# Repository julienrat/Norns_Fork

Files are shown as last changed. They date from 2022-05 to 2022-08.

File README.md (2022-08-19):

# Norns_Fork
**Dépôt Norns - installation Damien Skoraki**

L'idée principale est de forker l'officiel NORNS pour **la sublimer, la destructurer et la revisiter** avec un chapeau hifiberry DAC ADC Pro et des composants pas trop coûteux...

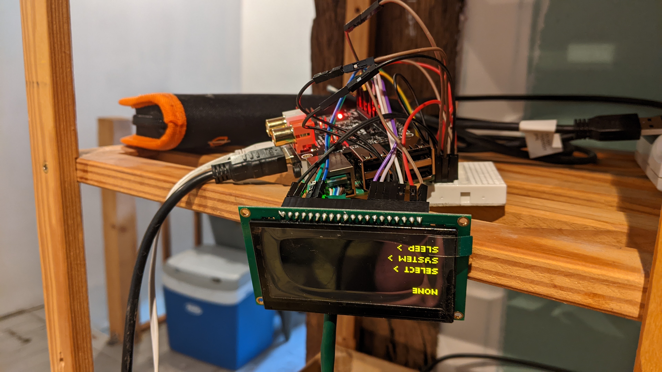
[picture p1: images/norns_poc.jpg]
Norns destructuré


La doc du HIFIBERRY est ici : (https://www.hifiberry.com/docs/software/configuring-linux-3-18-x/)

## Modification du Kernel Original
Le noyau original  de norns ne contient pas les modules permettant le bon fonctionnement du chapeau HIFIBERRY, mais contient les modules de l'ecran !

D'autres noyaux sont présents dans la distribution officielle de Norns .... mais sans les modules de l'écran !

D'où le casse tête ! donc 2 solutions !

- Recompiler un noyau vierge sur une install vierge au risque de louper des trucs en s'inspirant du [vieux tuto](https://github.com/okyeron/norns-image/wiki/1.-Norns-2.0-Full-Build-on-RasPi)
- Partir du  dernier noyau de l'installation y ajouter l'écran en bénéficiant des modules installés d'office pour ce noyau et garder tous les fichiers de config de l'installation en s'inpirant de ce [tuto vieux aussi :D](https://github.com/okyeron/norns-image/wiki/Reference:--Compile-OLED-display-drivers)

J'ai décidé de choisir la seconde option ! on pars de l'existant, on modifie le vieux tuto ! et si ça bouge ce sera facile d'upgrader une image des familles !

**DONC :**

À partir de la realease NORNS **norns 220306**  :

[Images SD Norns](https://github.com/monome/norns-image/releases)

On flash une carte SD avec le logiciel Balena ETCHER : 

[Balena Etcher](https://www.balena.io/etcher/)

### On se connecte en ssh
```
ssh we@<adresse_ip>
Mot de passe : sleep
```
On étend la partition pour travailler à l'aise !
```
sudo raspi-config
```
et on reboot !

### Installation des paquets de compilation 
```
sudo apt-get update
sudo apt-get upgrade
sudo apt-get install flex bison raspberrypi-kernel-headers
sudo apt install build-essential fakeroot dpkg-dev perl libssl-dev bc gnupg dirmngr libncurses5-dev libelf-dev 
```
### On commente la derniere ligne du fichier /boot/config.txt

On édite

```
sudo nano /boot/config.txt
```
On va commenter cette ligne pour lancer la derniere version du kernel connue ! et non celle bidouillée par NORNS

```
#kernel=gnagnagna
```
et pendant qu'on est sur le fichier, on va commenter la ligne :
```
#dtoverlay=monome-snd-4271
```
et ajouter ces deux lignes pour utiliser la carte son du hifiberry adcplusdac-pro
```
dtoverlay=hifiberry-dacplusadcpro
force_eeprom_read=0
```
et on reboot ! et on jete un coup d'oeil sur la carte hifiberry, normalement les leds rouges doivent scintiller...

### Récupération du noyau pour compiler les modules:

```
git clone --depth=1 https://github.com/raspberrypi/linux
```

### On compile
on va récupérer les fichiers de config
```
cp /usr/src/linux-headers-$(uname -r)/Module.symvers .
cp /usr/src/linux-headers-$(uname -r)/.config .
```
ensuite on lance le menuconfig
```
make menuconfig
```
et on active l'écran !

```
Device Drivers  ---> Staging Drivers ---> Support for small TFT LCD display modules  --->
        <M>   SH1106 driver
        <M>   SSD1322 driver
```
et enfin on compile !
```
make -j4 prepare

make -j4 -C ~/linux SUBDIRS=drivers/staging/fbtft modules

```
on attends 3-4 heures ...

### Copie des modules et test
On va copier les modules compilés au bon endroit
```
sudo cp -v ~/linux/drivers/staging/fbtft/*.ko /lib/modules/$(uname -r)/kernel/drivers/staging/fbtft/

sudo depmod -a
```
et zou on teste !
```
sudo modprobe fbtft custom name=fb_ssd1322 debug=1 speed=16000000 gpios=reset:15,dc:14
dmesg
```

### On va tweaker !
L'écran est desormais monté sur /dev/fb1 au lieu de /dev/fb0, il va falloir modifier la configuration de **matron** interface graphique, pour rediriger l'affichage sur le bon point de montage :

On édite

```
nano ~/norns/matronrc.lua
```
et on change la ligne 2 pour pointer sur /dev/fb1

```
_boot.add_io('screen:fbdev', {dev='/dev/fb1'})
```
On reboot et voilà !

### TWEAKS !
Pour changer le nom du Norns, il suffit d'editer le fichier hostname situé dans /etc/ 
```
sudo nano /etc/hostname
```
Modifier le nom , puis sauver en appuyant sur Ctrl+X puis Y pour sauver

Il est aussi possible de modifier le nom directement sur la carte SD en ouvrant le repertoire /etc

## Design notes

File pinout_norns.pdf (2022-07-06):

Feuille1

PIN MAP NORNS

Ecran OLED

ENC 1

1 3,3V | 1 | 2 | 5v | ENC 2
2 HIFIBERRY/SDA | 3 | 4 | 5v | ENC 3
3 HIFIBERRY/SCL | 5 | 6 | GND | HIFIBERRY
4 A1_ENC1 | 7 | 8 | RESERVEE | BP K1,K2,K3
5 GND | 9 | 10 | RESERVEE
6 | 11 | 12 | HIFIBERRY
7 B1_ENC1 | 13 | 14 | GND
8 K1_BP | 15 | 16 | B2_ENC2
9 3,3V | 17 | 18 | A2_ENC2
10 OLED_MOSI | 19 | 20 | GND
11 | 21 | 22 | B3_ENC3
12 SCK | 23 | 24 | CE_OLED
13 GND | 25 | 26
14 RESERVEE | 27 | 28 | RESERVEE
15 OLED_DC | 29 | 30 | GND
16 OLED_RESET | 31 | 32 | A3_ENC3
17 K3_BP | 33 | 34 | GND
18 HIFIBERRY | 35 | 36
19 K2_BP | 37 | 38 | HIFIBERRY
20 GND | 39 | 40 | HIFIBERRY

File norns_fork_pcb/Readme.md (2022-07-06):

# Dossier PCB Norns Syst et Norns Eko
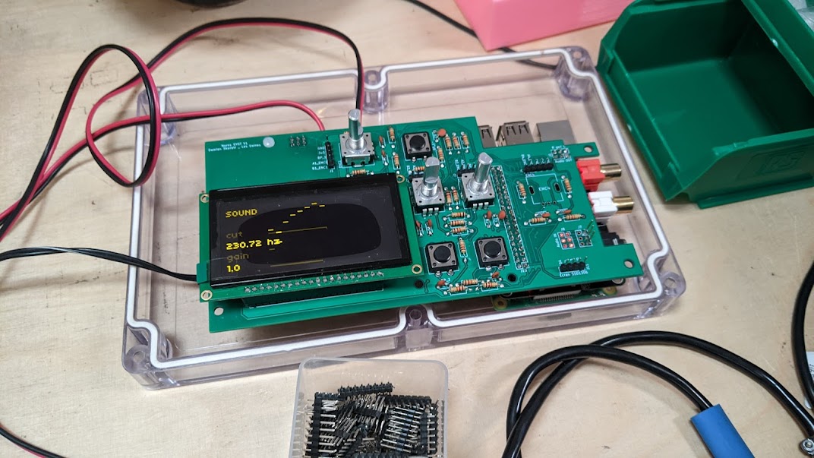
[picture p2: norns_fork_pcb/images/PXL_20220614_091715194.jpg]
Norns Syst


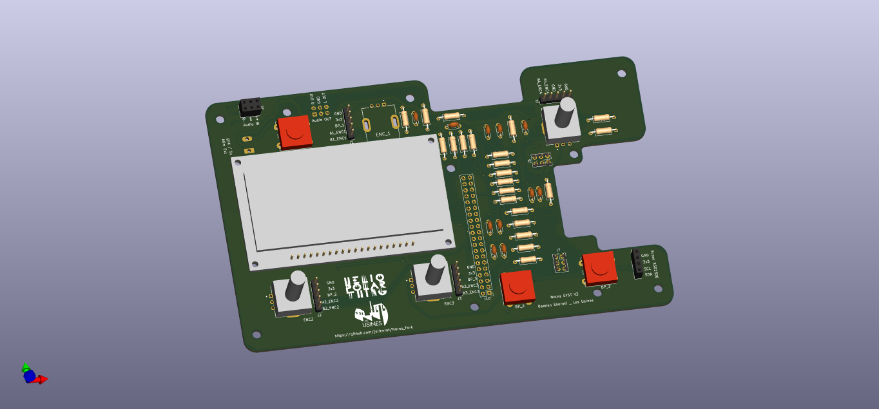
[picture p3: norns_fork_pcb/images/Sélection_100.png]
Norns Syst

## Instructions de soudure :

* Soudure SYST : [https://rawcdn.githack.com/julienrat/Norns_Fork/main/norns_fork_pcb/norns_SYST_kicad_sources/ibom.html]

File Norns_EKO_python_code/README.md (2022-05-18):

# Ici Tuto d'utilisation des modules TTGO

## Utilisation Basique
Le TTGO flashé possede une interface qu'il faut savoir prendre en main pour lancer ses scripts !

### Acces au menu de selection des scripts
Au démarrage du TTGO, appuyez sur le bouton droit, le menu de selection s'affiche alors.

A l'aide des boutons, sélectionnez le script désiré et sauvegardez en apuyant simultanément sur les deux boutons.

## Connexion à Thonny pour créer un script
A préalable, il faudra télécharger les drivers CH341 suivant votre systeme d'exploitation :

Puis installer le logiciel [thonny](https://thonny.org/)

## Connexion en WEBRPL

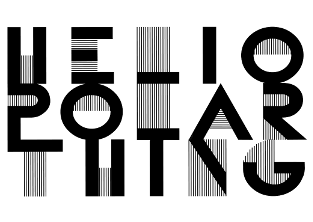
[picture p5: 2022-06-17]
images/visuel3-Small-1.png

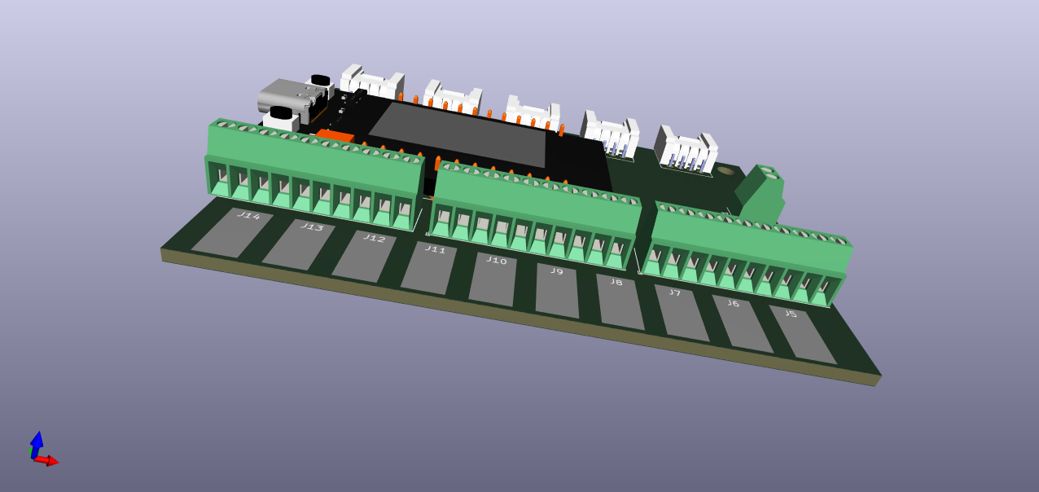
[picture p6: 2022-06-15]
norns_fork_pcb/images/norns_eko_2.png

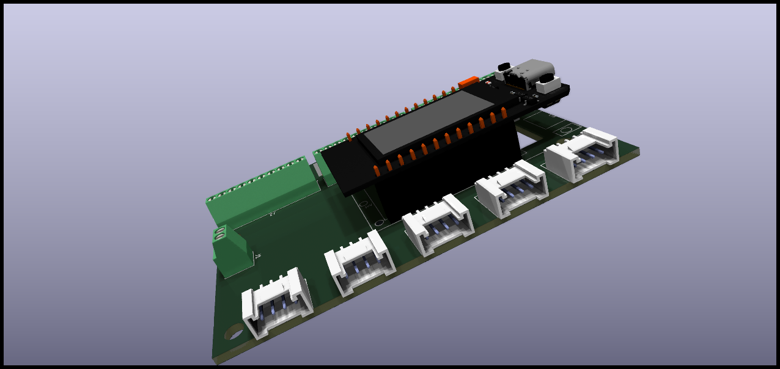
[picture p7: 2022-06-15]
norns_fork_pcb/images/norns_eko_support.png

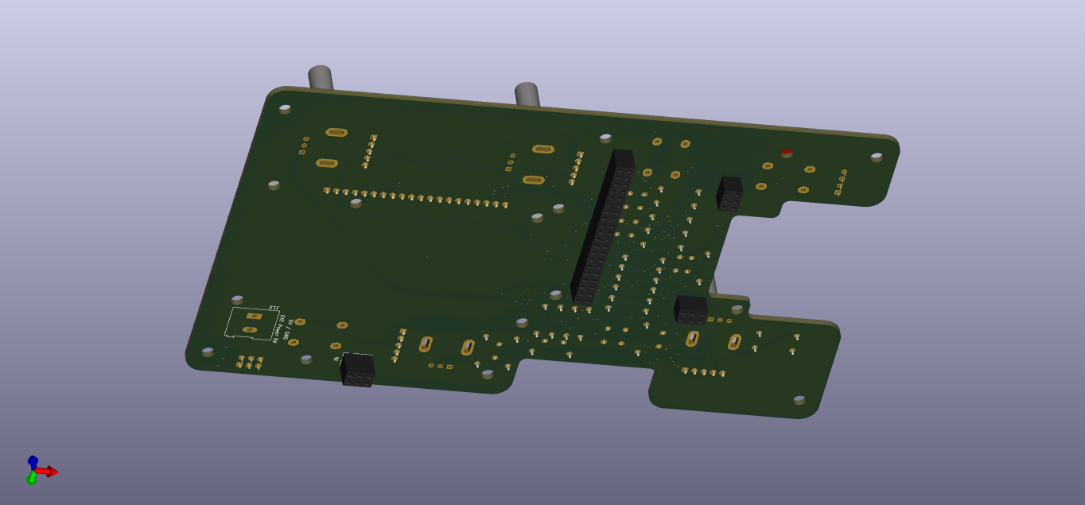
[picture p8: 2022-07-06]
norns_fork_pcb/images/Sélection_101.png

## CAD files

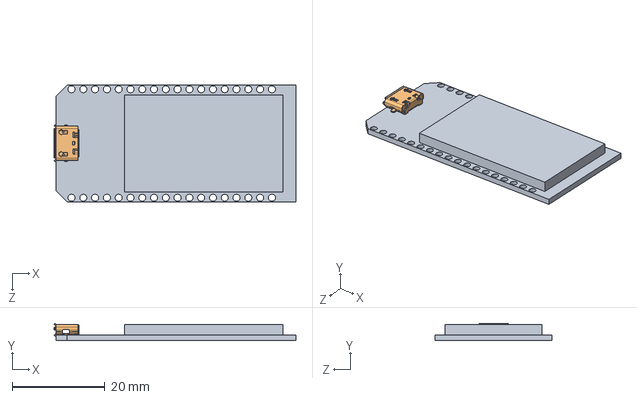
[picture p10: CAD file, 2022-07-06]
norns_fork_pcb/norns_EKO_kicad_sources/footprint/ttgo-tdisplay-kicad-master/TTGO1.SLDASM
52.1 x 3.77 x 25.1 mm
TTGO-ESP32LORA
microusb

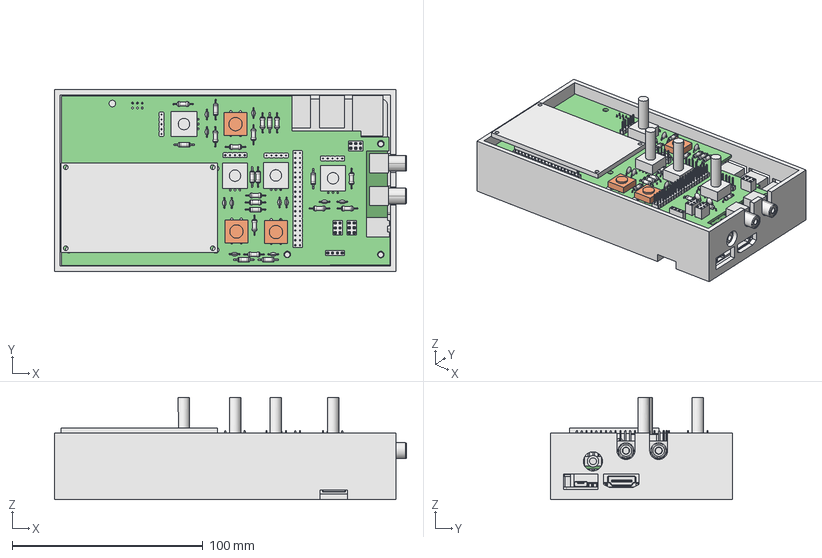
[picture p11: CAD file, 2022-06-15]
3D_case/3D_case_syst_freecad/test_2.FCStd
184.4 x 95.5 x 53.7 mm
_autosave-norns_fork PCB
RASPBERRY PI 3

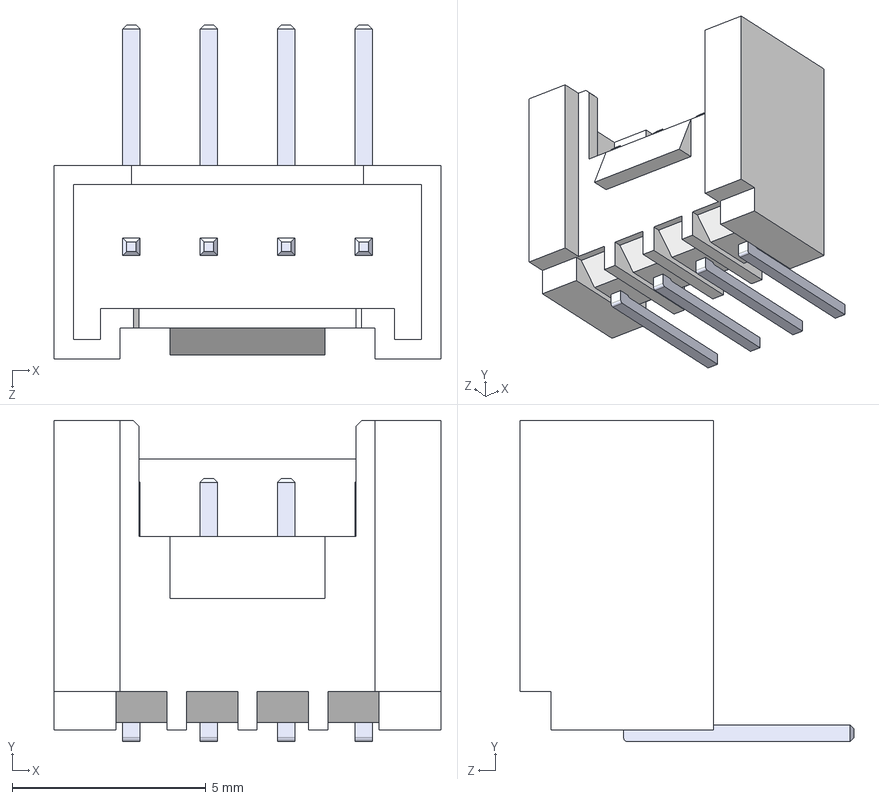
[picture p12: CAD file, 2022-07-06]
norns_fork_pcb/norns_EKO_kicad_sources/footprint/Grove Connector (lying).STEP
10.0 x 8.30 x 8.62 mm

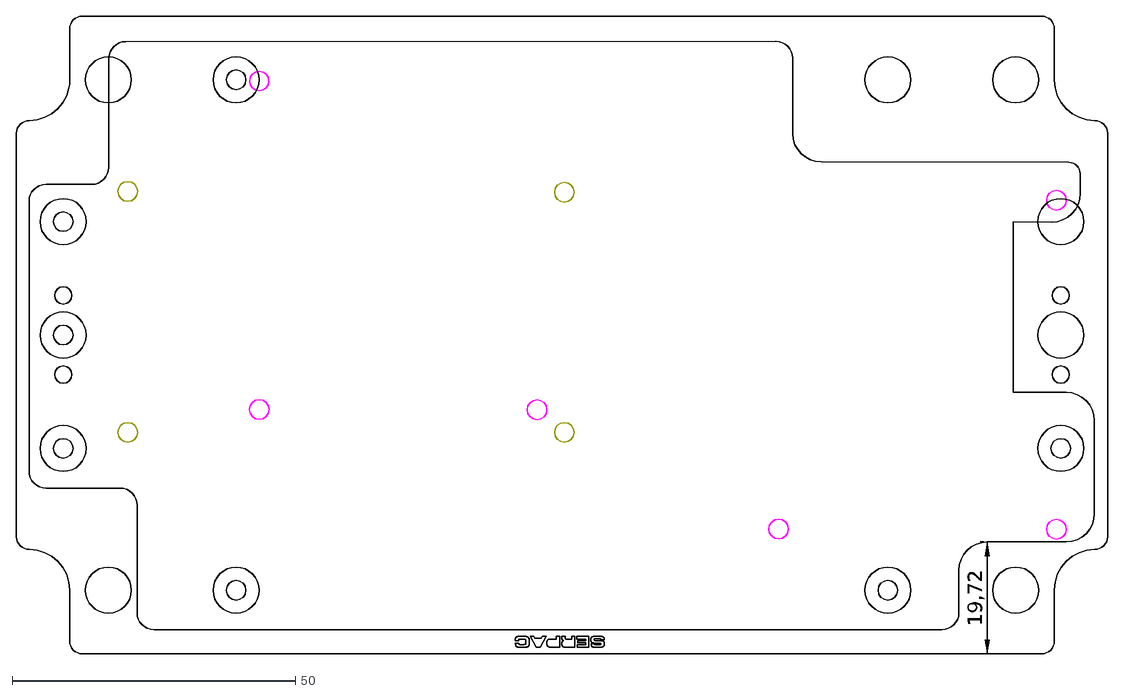
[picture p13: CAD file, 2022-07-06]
norns_fork_pcb/norns_SYST_kicad_sources/edgecut/#Fond boite_montage.dxf
19,72

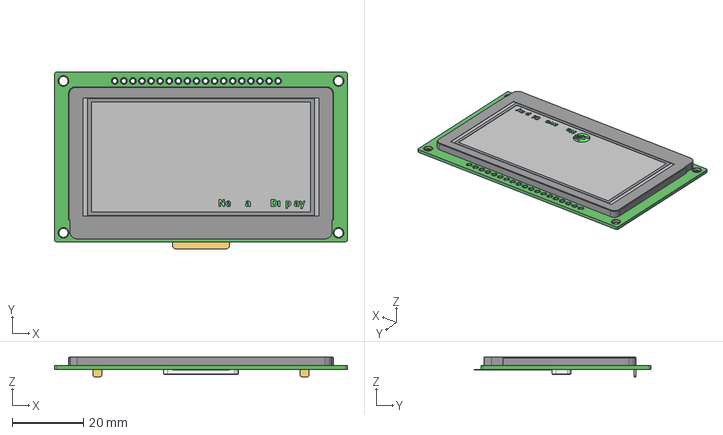
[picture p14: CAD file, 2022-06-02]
norns_fork_pcb/norns_SYST_kicad_sources/footprint/Disp_Newhaven Display_NHD-2.7-12864WDY3/eec.models/Newhaven_Display_-_NHD-2.7-12864WDY3.step
82.0 x 49.5 x 5.50 mm

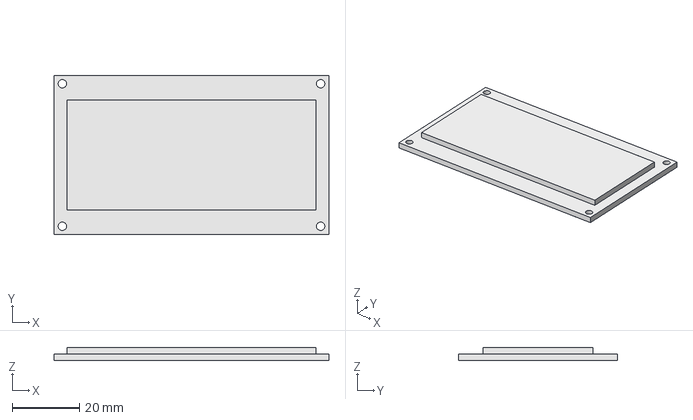
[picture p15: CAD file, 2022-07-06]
norns_fork_pcb/norns_SYST_kicad_sources/footprint/ecran.step
82.0 x 47.5 x 4.00 mm

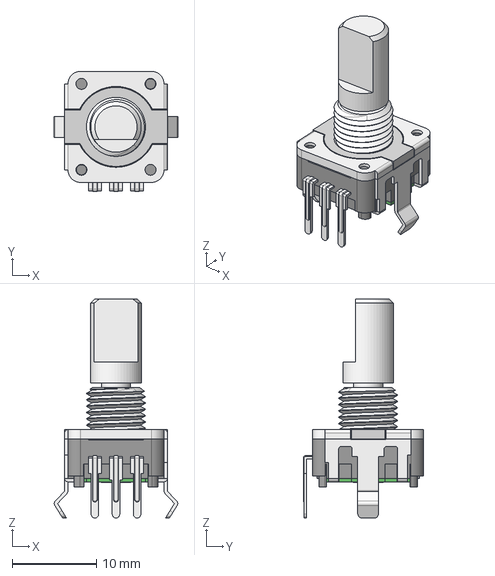
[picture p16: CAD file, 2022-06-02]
norns_fork_pcb/norns_SYST_kicad_sources/footprint/Enc_Bourns_PEC11R-4015F-N0024/eec.models/Bourns_-_PEC11R-4015F-N0024.step
14.7 x 14.3 x 26.0 mm

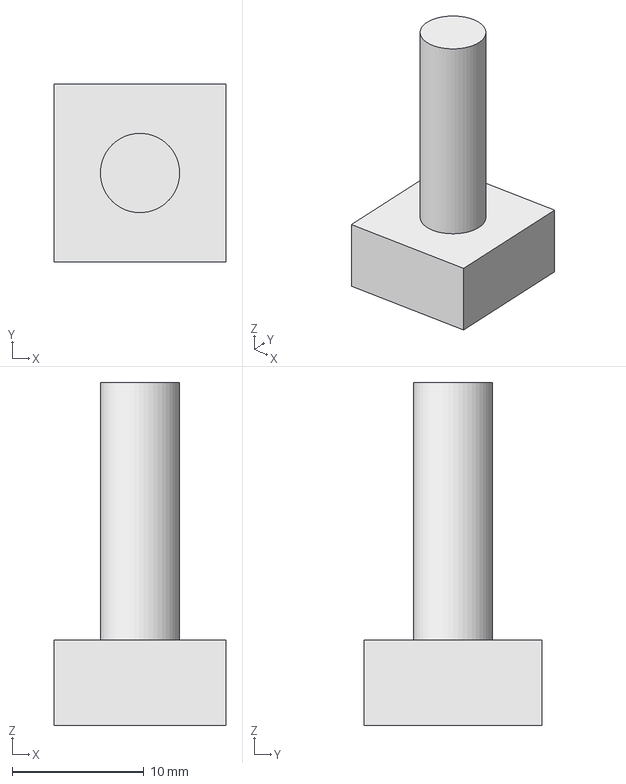
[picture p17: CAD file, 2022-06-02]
norns_fork_pcb/norns_SYST_kicad_sources/footprint/Enc_Bourns_PEC11R-4015F-N0024/encodeur.step
13.0 x 13.5 x 26.0 mm

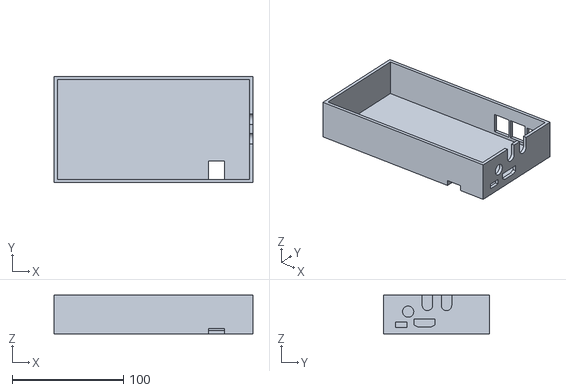
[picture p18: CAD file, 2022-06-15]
3D_case/3D_case_syst_freecad/test_2-Body.stl
178.7 x 95.3 x 35.0

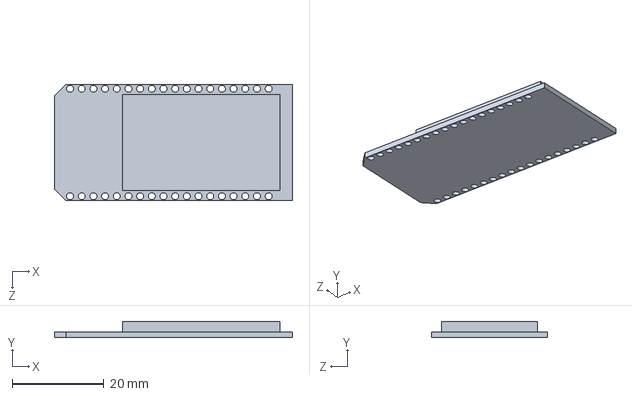
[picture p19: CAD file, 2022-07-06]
norns_fork_pcb/norns_EKO_kicad_sources/footprint/ttgo-tdisplay-kicad-master/TTGO-ESP32LORA.SLDPRT
51.8 x 3.55 x 25.1 mm

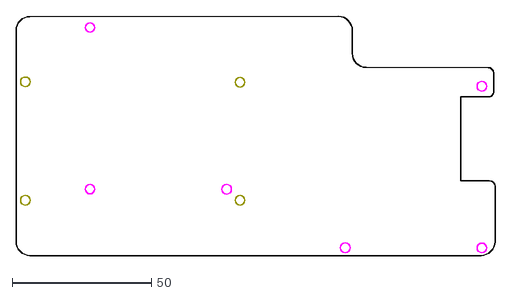
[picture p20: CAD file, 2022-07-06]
norns_fork_pcb/norns_SYST_kicad_sources/edgecut/norns_fork-Edge_Cuts.dxf
171.8 x 85.8

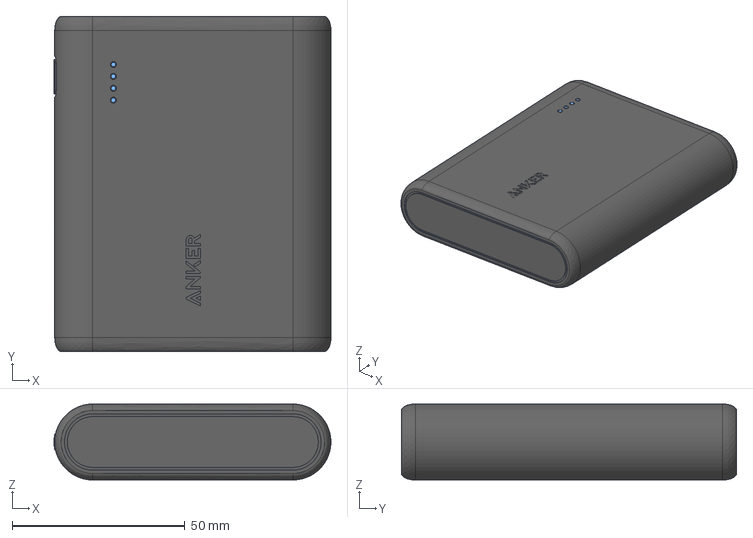
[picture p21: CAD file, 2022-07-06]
norns_fork_pcb/norns_SYST_kicad_sources/footprint/Anker Powercore 13000 Battery.step
80.2 x 97.0 x 22.0 mm

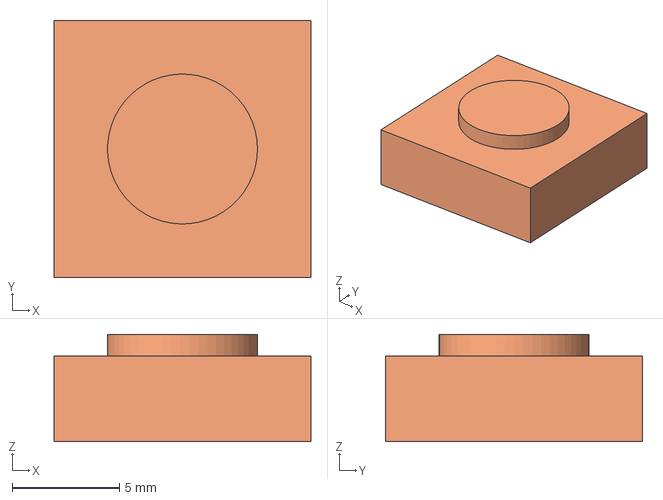
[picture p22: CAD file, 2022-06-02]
norns_fork_pcb/norns_SYST_kicad_sources/footprint/Enc_Bourns_PEC11R-4015F-N0024/bouton.step
12.0 x 12.0 x 5.00 mm

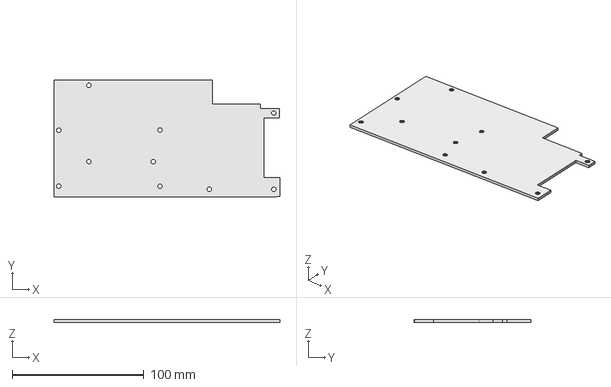
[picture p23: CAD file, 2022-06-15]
3D_case/3D_case_syst_freecad/test_1.FCStd
171.8 x 88.7 x 2.00 mm

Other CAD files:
norns_fork_pcb/norns_EKO_kicad_sources/footprint/ttgo-tdisplay-kicad-master/microusb.SLDPRT
norns_fork_pcb/norns_SYST_kicad_sources/edgecut/norns_fork-Edge_Cutsrnd.dxf
norns_fork_pcb/norns_SYST_kicad_sources/footprint/Enc_Bourns_PEC11R-4015F-N0024/ecran.step
norns_fork_pcb/norns_SYST_kicad_sources/footprint/rb85p12_24.step
3D_case/3D_case_syst_freecad/entretoises.FCStd
norns_fork_pcb/norns_SYST_kicad_sources/edgecut/#Fond boite.dxf
norns_fork_pcb/norns_SYST_kicad_sources/edgecut/Fond boite.dxf
norns_fork_pcb/norns_SYST_kicad_sources/edgecut/Fond boite_montage.dxf
norns_fork_pcb/norns_SYST_kicad_sources/edgecut/Norns_edgecut_final.dxf
norns_fork_pcb/norns_SYST_kicad_sources/edgecut/norns_fork-F_Silkscreen.dxf
norns_fork_pcb/norns_SYST_kicad_sources/footprint/RASPBERRY PI 3.STEP

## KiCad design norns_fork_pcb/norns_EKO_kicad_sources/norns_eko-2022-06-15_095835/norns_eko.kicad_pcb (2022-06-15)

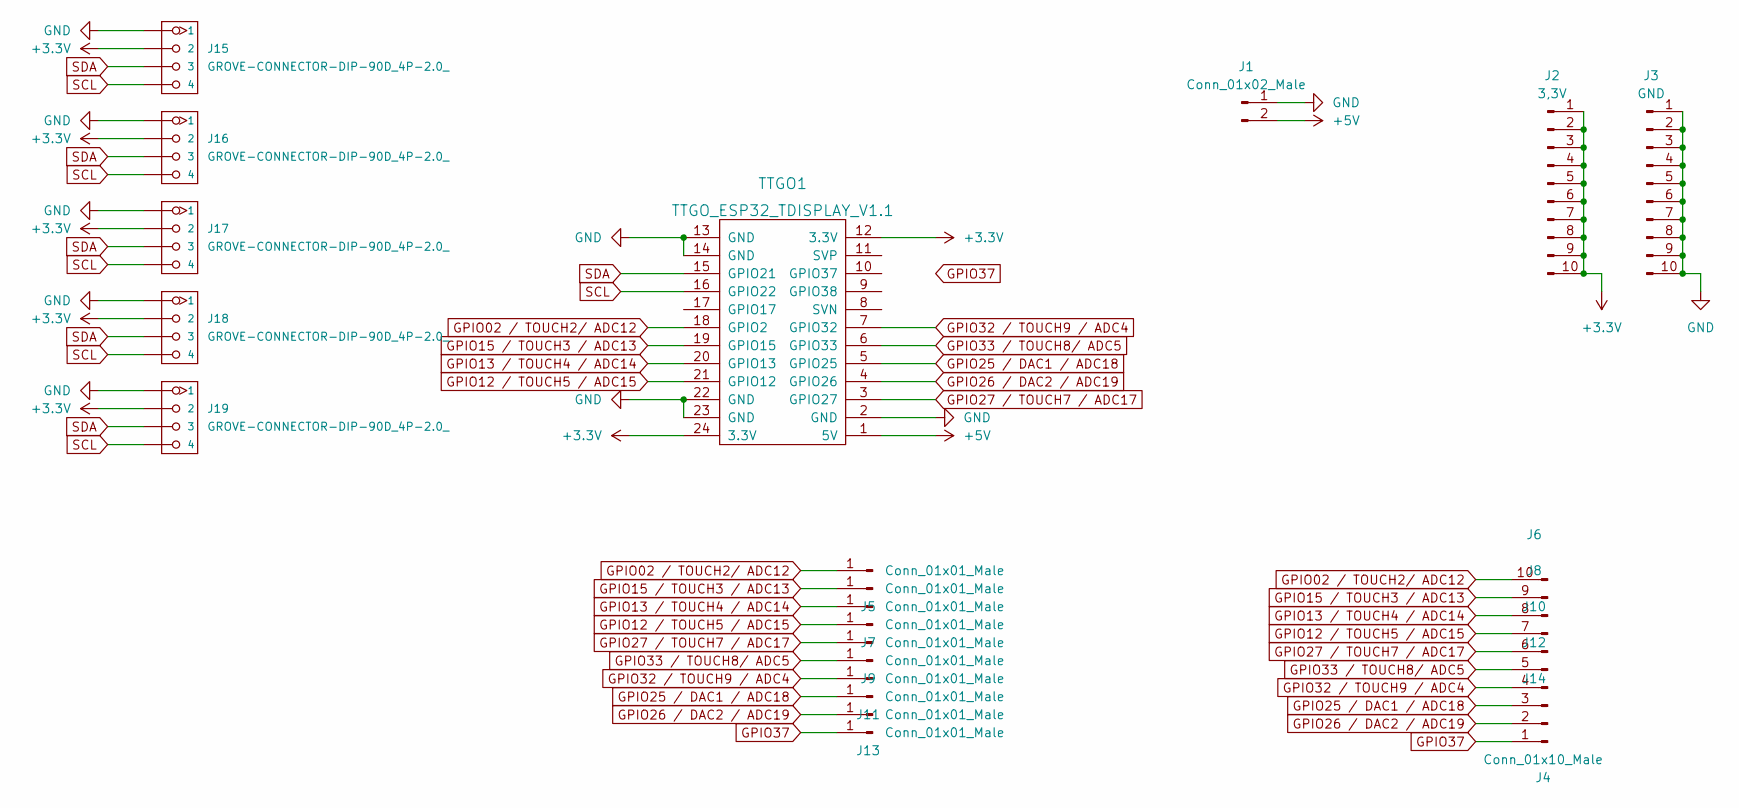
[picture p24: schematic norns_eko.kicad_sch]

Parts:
J1: Conn_01x02_Male; TerminalBlock_Phoenix_MPT-0,5-2-2.54_1x02_P2.54mm_Horizontal
J2: 3,3V; TerminalBlock_Phoenix_MPT-0,5-10-2.54_1x10_P2.54mm_Horizont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
J3: GND; TerminalBlock_Phoenix_MPT-0,5-10-2.54_1x10_P2.54mm_Horizont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
J4: Conn_01x10_Male; TerminalBlock_Phoenix_MPT-0,5-10-2.54_1x10_P2.54mm_Horizont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
J5, J6, J7, J8, J9, J10, J11, J12, J13, J14: Conn_01x01_Male; SolderWirePad_1x01_SMD_5x10mm
J15, J16, J17, J18, J19: GROVE-CONNECTOR-DIP-90D_4P-2.0_; HW4-2.0-90D
TTGO1: TTGO_ESP32_TDISPLAY_V1.1; TTGO_ESP32_TDisplay_v1.1

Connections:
+3V3: J2.1, J2.2, J2.3, J2.4, J2.5, J2.6, J2.7, J2.8, J2.9, J2.10, J15.2, J16.2, J17.2, J18.2, J19.2, TTGO1.12 (3.3V), TTGO1.24 (3.3V)
+5V: J1.2, TTGO1.1 (5V)
GND: J1.1, J3.1, J3.2, J3.3, J3.4, J3.5, J3.6, J3.7, J3.8, J3.9, J3.10, J15.1, J16.1, J17.1, J18.1, J19.1, TTGO1.2 (GND), TTGO1.13 (GND), TTGO1.14 (GND), TTGO1.22 (GND), TTGO1.23 (GND)
GPIO02 / TOUCH2/ ADC12: J4.10, J5.1, TTGO1.18 (GPIO2)
GPIO12 / TOUCH5 / ADC15: J4.7, J8.1, TTGO1.21 (GPIO12)
GPIO13 / TOUCH4 / ADC14: J4.8, J7.1, TTGO1.20 (GPIO13)
GPIO15 / TOUCH3 / ADC13: J4.9, J6.1, TTGO1.19 (GPIO15)
GPIO25 / DAC1 / ADC18: J4.3, J12.1, TTGO1.5 (GPIO25)
GPIO26 / DAC2 / ADC19: J4.2, J13.1, TTGO1.4 (GPIO26)
GPIO27 / TOUCH7 / ADC17: J4.6, J9.1, TTGO1.3 (GPIO27)
GPIO32 / TOUCH9 / ADC4: J4.4, J11.1, TTGO1.7 (GPIO32)
GPIO33 / TOUCH8/ ADC5: J4.5, J10.1, TTGO1.6 (GPIO33)
GPIO37: J4.1, J14.1
SCL: J15.4, J16.4, J17.4, J18.4, J19.4, TTGO1.16 (GPIO22)
SDA: J15.3, J16.3, J17.3, J18.3, J19.3, TTGO1.15 (GPIO21)

Board: 2 copper layers, 20 parts (0 on the bottom side), 15 nets, no tracks yet.

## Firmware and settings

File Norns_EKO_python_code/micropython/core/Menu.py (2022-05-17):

import lib.st7789py as st7789
import time #mostly fro sleep
from machine import Pin, SoftSPI, reset # for display and buttons
from fonts.romfonts import vga1_16x32 as font
import os
from lib.Button import Button


Button1_Pin = 35; #right button
Button2_Pin = 0;  #left button
val_button1=False
val_button2=False
list_files=0
menu_pos=0
menu_array=[]
windows=0

spi = SoftSPI(
        baudrate=20000000,
        polarity=1,
        phase=0,
        sck=Pin(18),
        mosi=Pin(19),
        miso=Pin(13))

display = st7789.ST7789(
    spi,
    135,
    240,
    reset=Pin(23, Pin.OUT),
    cs=Pin(5, Pin.OUT),
    dc=Pin(16, Pin.OUT),
    backlight=Pin(4, Pin.OUT),
    rotation=0)

display.fill(0)

def clean_menu():
    list_menu=os.listdir()
    list_menu.remove("main.py")
    list_menu.remove("boot.py")
    list_menu.remove("core")
    list_menu.remove("lib")
    list_menu.remove("fonts")
    global menu_array
    menu_array = list_menu
    return list_menu
    
def save(): #Sauvegarde de Main.py
    #display.fill(0)
    f = open('main.py', 'w')
    f2 = open('core/main.txt', 'w')
    command = menu_array[menu_pos]
    array_cmd= command.split(".")
    f.write("import "+array_cmd[0])
    f2.write(command)
    try:
        display.fill(0)
        display.text(font, menu_array[menu_pos]+"        ",0,0 ,st7789.color565(255, 0, 255),st7789.color565(0, 0, 0))
        display.hline(0,33,135,st7789.color565(255, 0, 255))
        display.hline(0,35,135,st7789.color565(255, 0, 255))
        display.text(font, "REBOOT",10,60 ,st7789.color565(255, 0, 0),st7789.color565(0, 0, 0))
        display.text(font, "WAIT",10,90 ,st7789.color565(255, 0, 0),st7789.color565(0, 0, 0))

    except :
        print("error")
    f.close()
    f2.close()
    time.sleep(2)
    reset()
    
def read(): #Sauvegarde de Main.py
    display.fill(0)
    f = open('core/main.txt', 'r')
    file_select = f.read()
    try:
        display.text(font, file_select,0,0 ,st7789.color565(255, 0, 255),st7789.color565(0, 0, 0))
        display.hline(0,33,135,st7789.color565(255, 0, 255))
        display.hline(0,35,135,st7789.color565(255, 0, 255))
    except :
        print("error")
    f.close()
    
def show_menu(pos):
    global list_files
    list_files = len(menu_array)
    for i in range(windows,list_files):
        if i == pos:
            try:
                display.text(font, menu_array[i]+"      ",0,40+(i-windows)*30,st7789.color565(155, 190, 0),st7789.color565(0, 0, 0))
            except :
                print("error")
        else:
            try:
                display.text(font, menu_array[i]+"      ",0,40+(i-windows)*30,st7789.color565(0, 0, 255),st7789.color565(0, 0, 0))
            except :
                print("error")

def menu_moins(p, event):
    global val_button2
    global windows
    if event == Button.RELEASED:
        global menu_pos
        menu_pos= menu_pos - 1
        if menu_pos < 0 :
            menu_pos=0            
        val_button2=False        
        if menu_pos<(windows+1) and windows>0:         
            windows-=1
            
        show_menu(menu_pos)
    if event == Button.PRESSED:        
        val_button2=True
        if val_button1 and val_button2:
            save()
    
def menu_plus(p, event):
    global val_button1
    global windows
    if event == Button.RELEASED:
        global menu_pos
        menu_pos= menu_pos + 1
        if menu_pos > list_files-1 :
            menu_pos = list_files-1
        val_button1=False
        if menu_pos>5:                        
            if windows<list_files-6:
                windows+=1
               
            
        show_menu(menu_pos)
    if event == Button.PRESSED:        
        val_button1=True
        if val_button1 and val_button2:
            save()

button1 = Button(Button1_Pin, callback = menu_plus, internal_pullup = True)
button2 = Button(Button2_Pin, callback = menu_moins, internal_pullup = True)

clean_menu()
read()
show_menu(menu_pos)

while True:
    button1.update()
    button2.update()
   

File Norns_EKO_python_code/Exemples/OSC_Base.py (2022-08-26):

from uosc.client import Bundle, Client, create_message
from time import sleep
import random
from machine import Pin,ADC, SoftSPI
import lib.st7789py as st7789
from fonts.romfonts import vga1_16x16 as font
from fonts.romfonts import vga1_8x8 as mini_font
    
###### Configuration générale

ip_adress = '192.168.0.33' #adresse ip du Norns defaut : 10.42.0.1
port = 10111 #port du Norns defaut : 10111
pot_1 = ADC(Pin(37)) #Broche du capteur analogique numero 1
pot_2 = ADC(Pin(38)) #Broche du capteur analogique numero 2
osc = Client(ip_adress, port) #demarrage du client OSC

####################### INITIALISATION AFFICHAGE
spi = SoftSPI(
        baudrate=20000000,
        polarity=1,
        phase=0,
        sck=Pin(18),
        mosi=Pin(19),
        miso=Pin(13))

display = st7789.ST7789(
    spi,
    135,
    240,
    reset=Pin(23, Pin.OUT),
    cs=Pin(5, Pin.OUT),
    dc=Pin(16, Pin.OUT),
    backlight=Pin(4, Pin.OUT),
    rotation=1)
################################ BOUTONS
Button1_STOP = 35; #Boutons pour coupure de la boucle
Button2_STOP = 0;
pin1 = Pin(Button1_STOP, Pin.IN, Pin.PULL_UP)
pin2 = Pin(Button2_STOP, Pin.IN, Pin.PULL_UP)
#################################################


while True :
    pot_1_value=pot_1.read()*11-3700 #Lecture de la broche capteur analogique 1
    pot_2_value=pot_2.read()*11-300 #Lecture de la broche capteur analogique 1
    random_value=random.uniform(0.1,3.2) #du rendom pour tester
    try : #on essaie d'envoyer les valeurs pour ne pas bbloquer le soft
        b = Bundle()
        b.add(create_message("/params/cutoff", random_value)) #envoi des valeurs en OSC        
        b.add(create_message("/params/release", pot_1_value)) #envoi des valeurs en OSC        
        b.add(create_message("/params/XXXX", pot_2_value)) #envoi des valeurs en OSC
        osc.send(b)
        
        display.text(mini_font, "WIFI OK               ",0,120 ,st7789.color565(24, 255, 0),st7789.color565(0, 0, 0))

    except Exception as e:
        print("ERROR : "+str(e))
        print(e)
        display.text(mini_font, "WIFI PB TRY TO CONNECT",0,120 ,st7789.color565(255, 0, 0),st7789.color565(0, 0, 0))
    ########## AFFICHAGE DANS THONNY ##########################
    print("Random value : ",random_value)
    print("Pot 1        : ",pot_1_value)
    print("Pot 2        : ",pot_2_value)
    ######## AFFICHAGE OLED #######################
    display.text(font, "ENVOI OSC ",0,0 ,st7789.color565(255, 0, 255),st7789.color565(0, 0, 0))
    display.text(mini_font, "--------------------",0,20 ,st7789.color565(0, 0, 255),st7789.color565(0, 0, 0))
    display.text(mini_font, "Rand  : "+str(random_value),0,30 ,st7789.color565(0, 0, 255),st7789.color565(0, 0, 0))
    display.text(mini_font, "Pot 1 : "+str(pot_1_value),0,45 ,st7789.color565(0, 0, 255),st7789.color565(0, 0, 0))
    display.text(mini_font, "Pot 2 : "+str(pot_2_value),0,60 ,st7789.color565(0, 0, 255),st7789.color565(0, 0, 0))
    ###############################################
    sleep(0.5)
    ################ QUITTER LA BOUCLE en appuyant sur un des deux boutons pour programmer
    if(pin1.value()==0 or pin2.value()==0):
        break

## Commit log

2022-05-17 Ajout des scripts TTGO T-display
2022-05-17 ajout du mapping de cablage
    [pinout_norns.ods]
2022-06-02 ajout du PCB
    [Bourns_-_PEC11R-4015F-N0024.step, Newhaven_Display_-_NHD-2.7-12864WDY3.step, bouton.step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]
2022-06-02 ajout de la BOM
    [norns_fork.csv]
2022-06-15 mise a jour
    [fichier 3D V2.FCStd, fichier 3D.FCStd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]
2022-06-15 ajout EKO
    [norns_eko.csv, norns_eko.kicad_pcb, norns_eko.kicad_sch]
2022-06-15 3D case for syst
    [RASPBERRY PI 3.STEP, entretoises.FCStd, test_1.FCStd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]
2022-06-15 3D case for syst modif
    [test_2.FCStd]
2022-06-15 Update PCB
2022-06-17 mise a jour du PCB
2022-06-23 ajout 3D
    [norns_forkV2.step]
2022-07-01 pcb_step v4
2022-07-01 ajout V3 du Norns
    [Bourns_-_PEC11R-4015F-N0024.step, Fond boite.dxf, Fond boite_montage.dxf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]
2022-07-06 mise a jour du dépot
    [#Fond boite.dxf, #Fond boite_montage.dxf, Anker Powercore 13000 Battery.step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]
2022-07-08 mise a jour du PCB avec les masques
    [norns_fork-B_Adhesive.gbr, norns_fork-B_Courtyard.gbr, norns_fork-B_Cu.gbr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]
2022-08-19 modif readme pour changement de nom norns
2022-08-19 timeout sur la connection wifi de 10 secondes
